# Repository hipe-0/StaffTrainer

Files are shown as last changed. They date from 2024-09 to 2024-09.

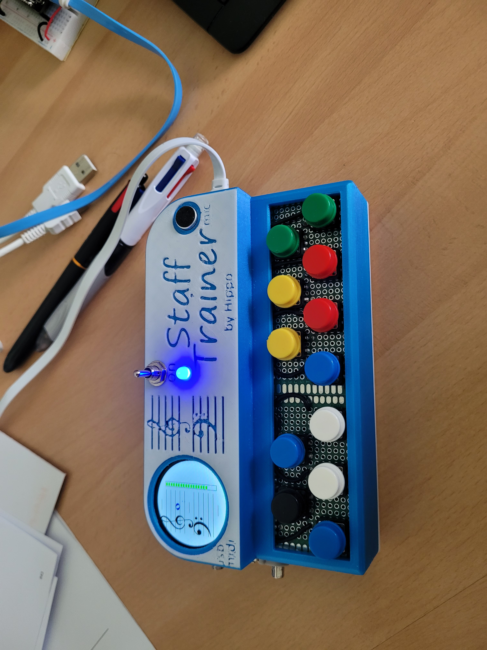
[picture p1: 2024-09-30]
medias/20240617_161333.jpg

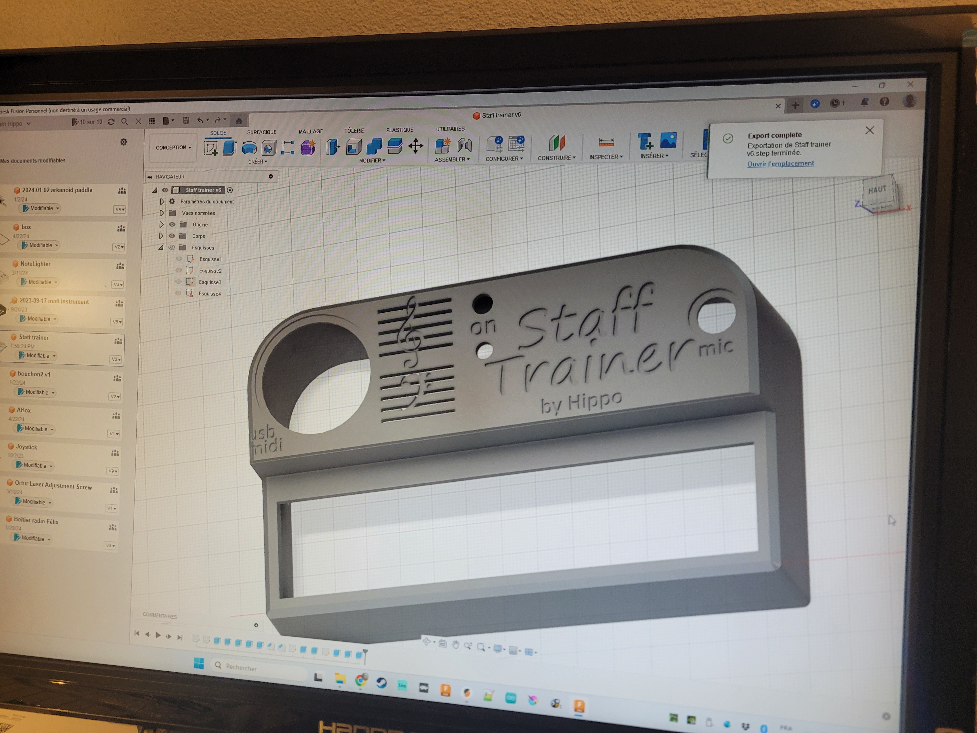
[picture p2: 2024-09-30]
medias/20240602_200722.jpg

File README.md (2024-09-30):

# StaffTrainer

Goal: This device teaches you the musical staff notation.
Kids-friendly and fun.

  

# Features
* On board 12 notes Keyboard
* Circular color screen 1.28 inch
* Midi host plug: so you can plug and play any midi instrument
* Microphone: audio pitch detection so you can play any instrument or sing
* Training on 4 octaves
* Training on A B C notation (USA)
* Training on do re mi notation (french)
* 20 Questions per exercise
* Get the 5 stars !
* Speed to get the correct answer is displayed as an average measured in seconds
* USB powered via micro usb cable
* Generates sound
* fully assembled, welded and tested by our highly motivated product development team as you can see :-)

Demo :

https://github.com/user-attachments/assets/d7a3c210-e539-4041-abc6-1f3a885aaadf

https://github.com/user-attachments/assets/febf5b2f-da8a-48bc-bd69-7ba0a03a5a47

#License: CC BY-NC
See https://creativecommons.org/licenses/by-nc/4.0/ This license enables reusers to distribute, remix, adapt, and build upon the material in any medium or format for noncommercial purposes only, and only so long as attribution is given to the creator. CC BY-NC includes the following elements:

BY: credit must be given to the creator. NC: Only noncommercial uses of the work are permitted.

# Bill of materials
* Teensy 4.1 microcontroller by PJRC (https://www.pjrc.com/store/teensy41.html)
* Audio shield for Teensy (https://www.pjrc.com/store/teensy3_audio.html)
* TFT screen 240x240 pixels GC9401A SPI 4x wires (similar to https://www.aliexpress.com/item/1005005555155161.html)
* 12 push buttons
* USB host cable with plug by PJRC (https://www.pjrc.com/store/cable_usb_host_t36.html)
* Microphone (diaphragm piezo 10mm diameter)
* USB cable 1 m :USB A male to micro USB male
* 3D Printed box + back cover (STP files are in the repository for easy printing yourself)
* 3W 8 Ohm mini loudspeaker (similar to https://www.aliexpress.com/item/1005005699882165.html)
* Amplifier board HW-104 3.3 v 2x3W (similar to https://www.aliexpress.com/item/1005006982225975.html)

# Analog Audio internal logic
Capture d'écran 2024-09-30 232830

Hippolyte

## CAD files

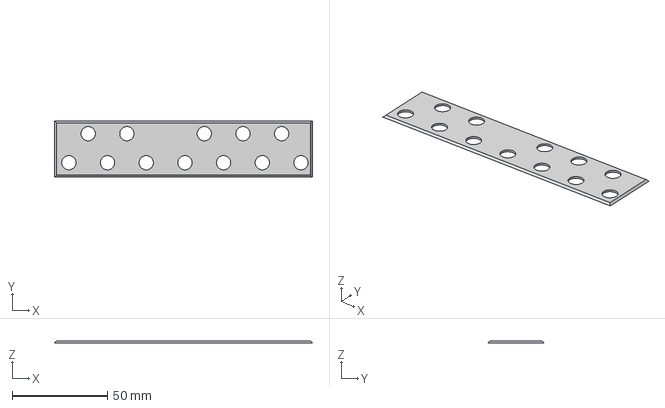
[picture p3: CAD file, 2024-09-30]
3Dprint/Staff trainer - Plaque de clavier v2.step
135.5 x 29.5 x 1.00 mm

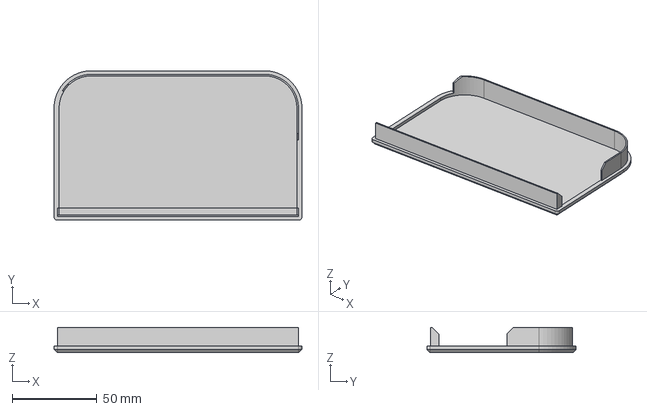
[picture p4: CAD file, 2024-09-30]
3Dprint/Staff trainer Backplate.step
146.0 x 88.0 x 15.0 mm

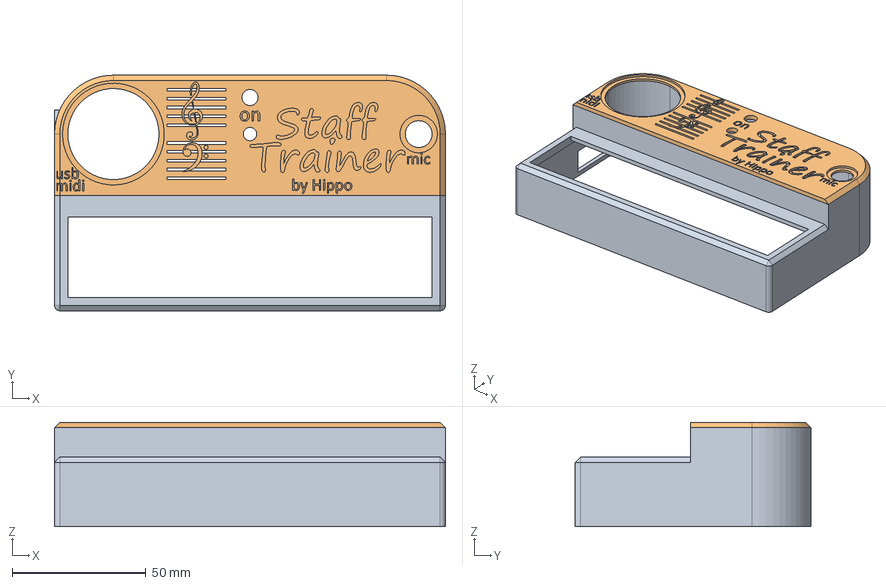
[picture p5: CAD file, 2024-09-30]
3Dprint/Staff trainer box.step
146.0 x 88.0 x 39.0 mm

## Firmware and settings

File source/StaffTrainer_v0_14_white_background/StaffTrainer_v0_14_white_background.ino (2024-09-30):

// StaffTrainer
// by Hippolyte Mounier
// 2024-05-20

#define APP_NAME "Staff Trainer"
#define APP_VERSION "v0.14"

#include "ButtonManager.h"
ButtonManager myButtons;

#include "DisplayManager.h"
DisplayManager myScreen;

#include "Trainer.h"
Trainer myTrainer;

#include "MidiUsbHostHandler.h"
MidiUsbHostHandler myMidi;

#include "AudioBeepMic.h"
AudioBeepMic myBeep;

void setup() {
  Serial.begin(115200);
  Serial.println(APP_NAME);

  myScreen.init();
  myBeep.init();

  myBeep.playBeep(0, 100);
  delay(200);
  myBeep.playBeep(12, 100);
  myBeep.playBeep(0, 100);

  myMidi.init();

  Serial.println("--------End Setup---------");
}

int prevState = -1;  // forces initial display update

void loop() {
  myButtons.loop();
  myMidi.loop();

  int state = myTrainer.getCurrentState();
  if (state != prevState) 
    manageDisplay();

  prevState = state;

  manageState(state);
}

void manageState(int state) {
  switch (state) {
    case MENU:
      if (myButtons.isPressed(0) || myMidi.isKeyPressed(0)) {
        myTrainer.newExercise(FRENCH_NOTATION, 20, 0, 11);
        myBeep.playBeep(0, 100);
      }

      if (myButtons.isPressed(2) || myMidi.isKeyPressed(2)) {
        myTrainer.newExercise(ENGLISH_NOTATION, 20, 0, 11);
        myBeep.playBeep(0, 100);
      }

      if (myButtons.isPressed(4) || myMidi.isKeyPressed(4)) {
        myTrainer.newExercise(STAFF_NOTATION, 20, 0, 11);
        myBeep.playBeep(0, 100);
        myScreen.clean();
      }

      if (myButtons.isPressed(5) || myMidi.isKeyPressed(5)) {
        myTrainer.newExercise(STAFF_NOTATION, 20, 12, 23);
        myBeep.playBeep(0, 100);
        myScreen.clean();
      }

      if (myButtons.isPressed(7) || myMidi.isKeyPressed(7)) {
        myTrainer.newExercise(STAFF_NOTATION, 20, -12, -1);
        myBeep.playBeep(0, 100);
        myScreen.clean();
      }

      if (myButtons.isPressed(9) || myMidi.isKeyPressed(9)) {
        myTrainer.newExercise(STAFF_NOTATION, 20, -24, -13);
        myBeep.playBeep(0, 100);
        myScreen.clean();
      }

      break;

    case EXERCISE_STOP:
      myBeep.playBeep(0, 100);
      myBeep.playBeep(4, 100);
      myBeep.playBeep(8, 100);
      myBeep.playBeep(12, 200);
      myTrainer.setState(CONGRAT);

      break;

    case CONGRAT:
      for (byte i = 0; i < BUTTON_NUM; i++)
        if (myButtons.isPressed(i) || myMidi.isKeyPressed(i))
          myTrainer.setState(MENU);

      break;

    case CORRECT_ANSWER:
      delay(100);
      myBeep.playBeep(myTrainer.getCurrentNoteValue(), 100);
      myTrainer.setState(ROLLING);  // rettriger a new note
      break;

    case WRONG_ANSWER:
      delay(100);
      myTrainer.setState(ASKING);  // no not rettriger a new note
      break;

    case ROLLING:
      delay(100 * rand() % 5);
      myTrainer.randomizeNote();
      myTrainer.setState(ASKING);  // forces back to "asking" state so that the display is triggered

      break;

    case ASKING:

      askingQuestion();
      break;
  }
}

void manageDisplay() {
  DEBUGVAL("myTrainer.getCurrentState()", myTrainer.getCurrentState())
  switch (myTrainer.getCurrentState()) {
    case MENU:
      myScreen.displayMenu();
      break;

    case CONGRAT:
      myScreen.displayCongratulation(myTrainer.getLastAverageTimeSeconds(), myTrainer.getCurrentExerciseTxt());
      break;

    case ASKING:
      displayNoteNormally();
      break;

    case CORRECT_ANSWER:
      displayNoteNormally();
      myScreen.writeTextLine2("Good!");
      break;

    case WRONG_ANSWER:
      displayNoteNormally();
      // display wrong answer message
      char phrase2[20] = "That's ";
      char* pressedNoteName = myTrainer.getNoteName(myTrainer.getLastNotePressed());
      strcat(phrase2, pressedNoteName);
      myScreen.writeTextLine2(phrase2);
      break;
  }
}

void displayNoteNormally() {

  switch (myTrainer.getCurrentExercise()) {
    case FRENCH_NOTATION:
    case ENGLISH_NOTATION:
      myScreen.clean();
      myScreen.writeText(myTrainer.getCurrentNoteName());
      myScreen.displayProgressbar(myTrainer.getNbResponses(), myTrainer.getMaxResponses());
      break;

    case STAFF_NOTATION:
      
      myScreen.eraseNoteOnStaff();
      myScreen.displayStaff();

      NoteHeight n = myTrainer.getNoteOnStaff(myTrainer.getCurrentNoteValue());
      myScreen.displayNoteOnStaff(n.noteOnStaff, n.extension);
      myScreen.displayProgressbarVertical(myTrainer.getNbResponses(), myTrainer.getMaxResponses());
      break;
  }
}

void askingQuestion() {
  char* currentNoteName = myTrainer.getCurrentNoteName();
  int noteHeard = myBeep.getMicHearingNote();
  if (noteHeard > -100)
    myTrainer.checkAnswer(noteHeard);


  for (byte i = 0; i < BUTTON_NUM; i++)
    if (myButtons.isPressed(i) || myMidi.isKeyPressed(i)) {
      Serial.print("The piano key ");
      Serial.print(i + 1);
      Serial.println(" is pressed");

      myTrainer.checkAnswer(i);
    }
}

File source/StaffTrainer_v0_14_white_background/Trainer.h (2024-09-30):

// Trainer.h
// by Hippolyte Mounier
// 2024-05-20
//
// Goal: manages the musical logic of the training, no display, no button management

#include "iferror.h"
enum TrainerStates { MENU,
                     ROLLING,
                     ASKING,
                     CORRECT_ANSWER,
                     WRONG_ANSWER,
                     EXERCISE_STOP,
                     CONGRAT };


enum Exercises { FRENCH_NOTATION,
                 ENGLISH_NOTATION,
                 STAFF_NOTATION };

struct NoteHeight {
  int noteOnStaff;
  char* extension;
};


#define MAX_RESPONSES 100

class Trainer {
private:
  int currentNote_ = 0;
  enum TrainerStates currentState_;
  enum Exercises currentExercise_;
  int minNote_ = 0;
  int maxNote_ = 11;
  unsigned long startMillis_;
  long lastAverageTime_ = 0;
  int lastPianoNotePressed_ = 0;
  bool isCurrentlyInFlatMode_ = true;

  char* noteNames_[12] = { "do", "do#", "re", "re#", "mi", "fa", "fa#", "sol", "sol#", "la", "la#", "si" };
  char* noteNamesFlats_[12] = { "do", "reb", "re", "mib", "mi", "fa", "solb", "sol", "lab", "la", "sib", "si" };

  char* noteNamesEN_[12] = { "C", "C#", "D", "D#", "E", "F", "F#", "G", "G#", "A", "A#", "B" };
  char* noteNamesENFlats_[12] = { "C", "Db", "D", "Eb", "E", "F", "Gb", "G", "Ab", "A", "Bb", "B" };

  int noteOnStaff_[12] = { 0, 0, 1, 1, 2, 3, 3, 4, 4, 5, 5, 6 };
  int noteOnStaffFlats_[12] = { 0, 1, 1, 2, 2, 3, 4, 4, 5, 5, 6, 6 };

  char* exercisesTxt_[6] = {
    "French notation",
    "English notation",
    "Staff notation",
    "Staff +1 octave",
    "Staff -1 octave",
    "Staff -2 octave"
  };

  int nbResponses_;
  int maxResponses_;
  long lastResponseTimes_[MAX_RESPONSES];

  long computeAverageTime_() {
    if (nbResponses_ == 0) return -1;  // error code if no score

    long averageTime = 0;
    for (int i = 0; i < nbResponses_; i++)
      averageTime += lastResponseTimes_[i];

    averageTime = averageTime / nbResponses_;

    return averageTime;
  }

  char lastChar_(char* string) {
    int len = strlen(string);
    return string[len - 1];
  }

  int moduloBy12_(int x) {  // modulo, remainer of the division by 12
    if (x > 0)
      return x % 12;
    else
      return (x + 96) % 12;  // avoid device dependent overflow that happens with negative operand value.
  }


public:

  Trainer() {
    DEBUGTXT("Trainer Init started")

    maxResponses_ = MAX_RESPONSES;
    currentState_ = MENU;
    currentExercise_ = FRENCH_NOTATION;
  }

  void setState(enum TrainerStates state) {
    currentState_ = state;
  }

  void newExercise(enum Exercises exercice, int maxResponses, int minNote, int maxNote) {
    IFERROR(maxResponses > MAX_RESPONSES, "Maximum number of responses reached")
    maxResponses_ = maxResponses;
    currentExercise_ = exercice;
    minNote_ = minNote;
    maxNote_ = maxNote;
    restartTraining();
  }

  void stopExercise() {
    if (currentState_ = ASKING)
      lastAverageTime_ = computeAverageTime_();

    currentState_ = EXERCISE_STOP;
  }

  void restartTraining() {
    if (currentState_ = ASKING)
      lastAverageTime_ = computeAverageTime_();

    nbResponses_ = 0;  // reseting the counter
    startMillis_ = millis();
    srand(millis());
    currentState_ = ROLLING;
  }


  int getCurrentState() {
    return currentState_;
  }

  void randomizeNote() {

    int old = currentNote_;
    //  find a new note that is different than the previous one
    do {
      currentNote_ = minNote_ + rand() % (maxNote_ - minNote_ + 1);
    } while (currentNote_ == old);

    isCurrentlyInFlatMode_ = rand() % 2;

    DEBUGVAL("New randomized note", currentNote_);
  }

  int getCurrentNoteValue() {
    return currentNote_;
  }

  char* getCurrentNoteName() {
    return getNoteName(currentNote_);
  }

  char* getNoteName(int i) {
    i = moduloBy12_(i);

    if (currentExercise_ == FRENCH_NOTATION)
      if (isCurrentlyInFlatMode_)
        return noteNamesFlats_[i];
      else
        return noteNames_[i];
    else if (isCurrentlyInFlatMode_)
      return noteNamesENFlats_[i];
    else
      return noteNamesEN_[i];
  }

  NoteHeight getNoteOnStaff(int i) {
    int i2 = moduloBy12_(i);
    int ioct = (i - i2) / 12;

    NoteHeight n = { 0, " " };

    if (isCurrentlyInFlatMode_) {
      char extension = lastChar_(noteNamesENFlats_[i2]);
      DEBUGVAL("extension", extension)
      if (extension == 'b')
        n.extension = "b";

      n.noteOnStaff = noteOnStaffFlats_[i2] + ioct * 7;
      DEBUGVAL2("n.noteOnStaff", n.noteOnStaff, "n.extention", n.extension)
      DEBUGVAL("getNoteName(i)", getNoteName(i))
      return n;
    }

    else {  // currently in Sharp mode
      char extension = lastChar_(noteNamesEN_[i2]);
      DEBUGVAL("extension", extension)
      if (extension == '#')
        n.extension = "#";

      n.noteOnStaff = noteOnStaff_[i2] + ioct * 7;
      DEBUGVAL2("n.noteOnStaff", n.noteOnStaff, "n.extention", n.extension)
      DEBUGVAL("getNoteName(i)", getNoteName(i))
      return n;
    }
  }


  bool checkAnswer(int buttonPressed) {
    lastPianoNotePressed_ = buttonPressed;

    DEBUGVAL2("currentNote_", currentNote_, "buttonPressed", buttonPressed)

    if (moduloBy12_(buttonPressed) == moduloBy12_(currentNote_))  // match is found
    {
      currentState_ = CORRECT_ANSWER;
      if (nbResponses_ < maxResponses_) {
        lastResponseTimes_[nbResponses_++] = millis() - startMillis_;
        startMillis_ = millis();  // restart counter
      } else
        stopExercise();

      return true;
    } else {
      currentState_ = WRONG_ANSWER;
      return false;
    }
  }

  float getLastAverageTimeSeconds() {
    return lastAverageTime_ * 0.001;
  }

  int getNbResponses() {
    return nbResponses_;
  }

  int getMaxResponses() {
    return maxResponses_;
  }

  int getLastNotePressed() {
    return lastPianoNotePressed_;
  }

  enum Exercises getCurrentExercise() {
    return currentExercise_;
  }

  char* getCurrentExerciseTxt()
  {
    return exercisesTxt_[currentExercise_];
  }
};
